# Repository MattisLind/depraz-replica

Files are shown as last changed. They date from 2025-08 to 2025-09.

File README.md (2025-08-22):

# Depraz mouse replica

Based on the work by John Floren this project is aiming at creating a modern replica of the Depraz mouse. A mouse that outputs quadrature signals exactly as the original.

The physical 3D model will be the same as the Bellwether mouse by John but the circuit board is replaced. The new circuitboard is going to use an STM32F103 micro controller. Since this processor is using 3.3V IO no level shifters are necessary. On the board there will be a 3.3V LDO regulator and a 2.0V regulator, STM32F103 with 8MHz crystal and the PMW3389 mouse chip. The outputs from the STM32F103 to the host are using open drain to be able to handle 5V outputs. 

# Old Bellwether project

This repo should contain everything you need to make a [Bellwether mouse](https://jfloren.net/bellwether.html).

Note that I've made several of these myself, but it's possible that I've forgotten a step or component somewhere.

I'm willing to answer questions to the best of my ability. I'll also consider assembling some portions of the mouse and mailing it out; send me an email if you want this.

The 3d models and the circuit are CC BY-NC-SA licensed. I believe this means that "group buys" (where 1 person coordinates ordering a bunch of PCBs and parts) are ok under this model.

## 3D-printed case

Inside the case/ subdirectory you'll find two FreeCAD files, "base" (the bottom part of the mouse) and "body" (the curved top which fits in your hand).

These should be printed in PLA. I've had good luck with my Prusa Mini. I strongly suggest using a raft when printing the body, and *not* using a raft for the base.

Check out the releases for pre-built STL files.

## PCB

The board was designed using KiCAD. If you use OSH Park, you should be able to just upload board/depraz_board.kicad_pcb directly on their site. For other PCB services, you may need to open KiCAD and export Gerber files etc.

## Circuit & BOM

You can check out the schematic in schematic.pdf

bom.csv is a circuit bill of materials. Most stuff should be available from parts companies in the US, but for the PMW3389 sensor you'll probably need to go to AliExpress (e.g. https://www.aliexpress.us/item/2251832705021246.html)

You'll also need 3 momentary pushbutton switches such as https://www.digikey.com/en/products/detail/5501M1BLKX/EG1701-ND/101654

Although you don't have to, I recommend using a DIP socket for the microcontroller in case you toast the microcontroller.

## Assembly

### Circuit assembly

In general it's all pretty straightforward but I strongly recommend installing the SMD level shifters first, all the rest of the components next, and then do the mouse sensor *last*.

### Doing the switches

I recommend gluing down the switches first. Gently pry off the button from each switch and set it aside. Then put a small dab of Gorilla Glue in the slot on the base, press the switch onto it, and make sure it's aligned straight. Use a clamp to hold the switch in place while the glue dries (I used something like https://www.amazon.com/Professional-Plastic-Backdrop-Photography-Improvement/dp/B08RXW32H4/). Once the glue is dry, make sure the switch is firmly seated and use an exacto knife to trim away any glue which oozed out, then press the button back onto the switch face.

Solder two wires onto each switch, on the normally-open pins. The wires should have Dupont pin connectors on the ends; I just took some jumper wires I had lying around (with a connector on each end) and cut them in half. See http://jfloren.net/content/bellwether/base2.jpg

### Physical assembly

You'll need the following parts to assemble the case:

* 8x M2x0.4mm heatserts: https://www.mcmaster.com/94459A120/
* 4x M2x0.4mm flathead screws (for the bottom): https://www.mcmaster.com/91294A003/
* 4x M2x0.4mm button head screws (to hold the board down): https://www.mcmaster.com/92095A451/

Additional stuff you'll want:

* A USB cable. Should be USB-A on one end, and a female pin header connector at the other. You can start with https://www.digikey.com/en/products/detail/assmann-wsw-components/A-USB20AM-OE-200BK28/10408422 and use https://www.amazon.com/Taiss-Ratcheting-Connector-Crimping-Terminal/dp/B0B11RLGDZ to crimp on a 4-pin header to the other end. You may be able to find these pre-made, e.g. https://www.amazon.com/dp/B07ZPT2NMT
* Friction tape (https://www.amazon.com/gp/product/B0000CBIAT) to wrap around the USB cable where it leaves the mouse. This appears to be what my original Depraz mouse used.
* Teflon tape to make skates for the bottom. I used https://www.amazon.com/gp/product/B01LZ44P6M and punched out pieces using https://www.amazon.com/gp/product/B00006IBK9

Use your soldering iron to install the heatserts flush in the corresponding holes of the case.

Position the lens on the bottom of the mouse sensor, then set the PCB on the 3d printed base. Use the button-head screws to hold down the PCB; don't overtighten!

Plug in the switches. Note that the headers on the board are labeled R, M, and L for right, middle, and left.

Plug the USB cable into the 4-pin USB header. Lay it across the board to where the cable hole in the case will go; mark this point and put a layer or two of friction tape on the cable there.

Gently slide the top of the case over the switches; there's a "right way" to do it, which takes a bit of gentle experimentation to find. Once you get the two pieces together, use flathead screws to hold them together.

Punch out four pieces of Teflon tape and stick them to the bottom for skates.

### Flashing the firmware

The firmware organization sucks, but I am not good enough at PIC programming to properly clean it up. PRs welcome.

Plug your PIC programmer into the PROGRAM header on the board.

Open MPLAB X IDE and load firmware/depraz/apps/usb/device/hid_mouse/firmware/low_pin_count_usb_development_kit_pic16f1459.x

I found that it worked when I set up the PICkit3 to provide power at 3.5V. Your other option is to plug in the USB cable before programming to power the device externally.

### Adding heft

You'll probably find that the mouse by itself is way too light. I hot-glued a bunch of lead fishing weights to the inside and it was much more pleasant.

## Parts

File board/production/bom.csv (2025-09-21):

Designator | Footprint | Quantity | Value | LCSC Part #
C1, C2, C3 | 1206 | 3 | 4.7u | C29823
C10, C11, C12, C15, C4, C9 | 0402 | 6 | 100n | C1525
C14, C5 | 0805 | 2 | 1u | C28323
C6, C7 | 0402 | 2 | 20p | C1554
C8 | CP_Elec_4x5.4 | 1 | 22u | C3356
D1 | 0603 | 1 | 1.9V PWR | C2286
D2 | 0805 | 1 | 3.3V PWR | C2297
D3 | 0805 | 1 | LED | C2296
J1 | PinHeader_1x06_P2.54mm_Vertical | 1 | Switches
J2 | PinHeader_1x09_P2.54mm_Vertical | 1 | Host
J3 | PinHeader_1x04_P2.54mm_Vertical | 1 | SWD
J4 | PinHeader_1x04_P2.54mm_Vertical | 1 | SERIAL
R1, R10, R2, R3, R5, R6, R7, R8, R9 | 0402 | 9 | 2k | C4109
R11 | 0603 | 1 | 47 | C23182
R13, R14 | 0402 | 2 | 510 | C25123
R4 | 0805 | 1 | 13 | C25282
U1 | WSON-6-1EP_2x2mm_P0.65mm_EP1x1.6mm | 1 | TLV75519PDRV | C2861631
U2 | WSON-6-1EP_2x2mm_P0.65mm_EP1x1.6mm | 1 | TLV75533PDRV | C2861750
U5 | pmw3389 | 1 | PMW3389DM
U6 | LQFP-48_7x7mm_P0.5mm | 1 | STM32F103C8Tx | C8734
Y1 | Crystal_SMD_HC49-SD | 1 | 8MHz | C20617538

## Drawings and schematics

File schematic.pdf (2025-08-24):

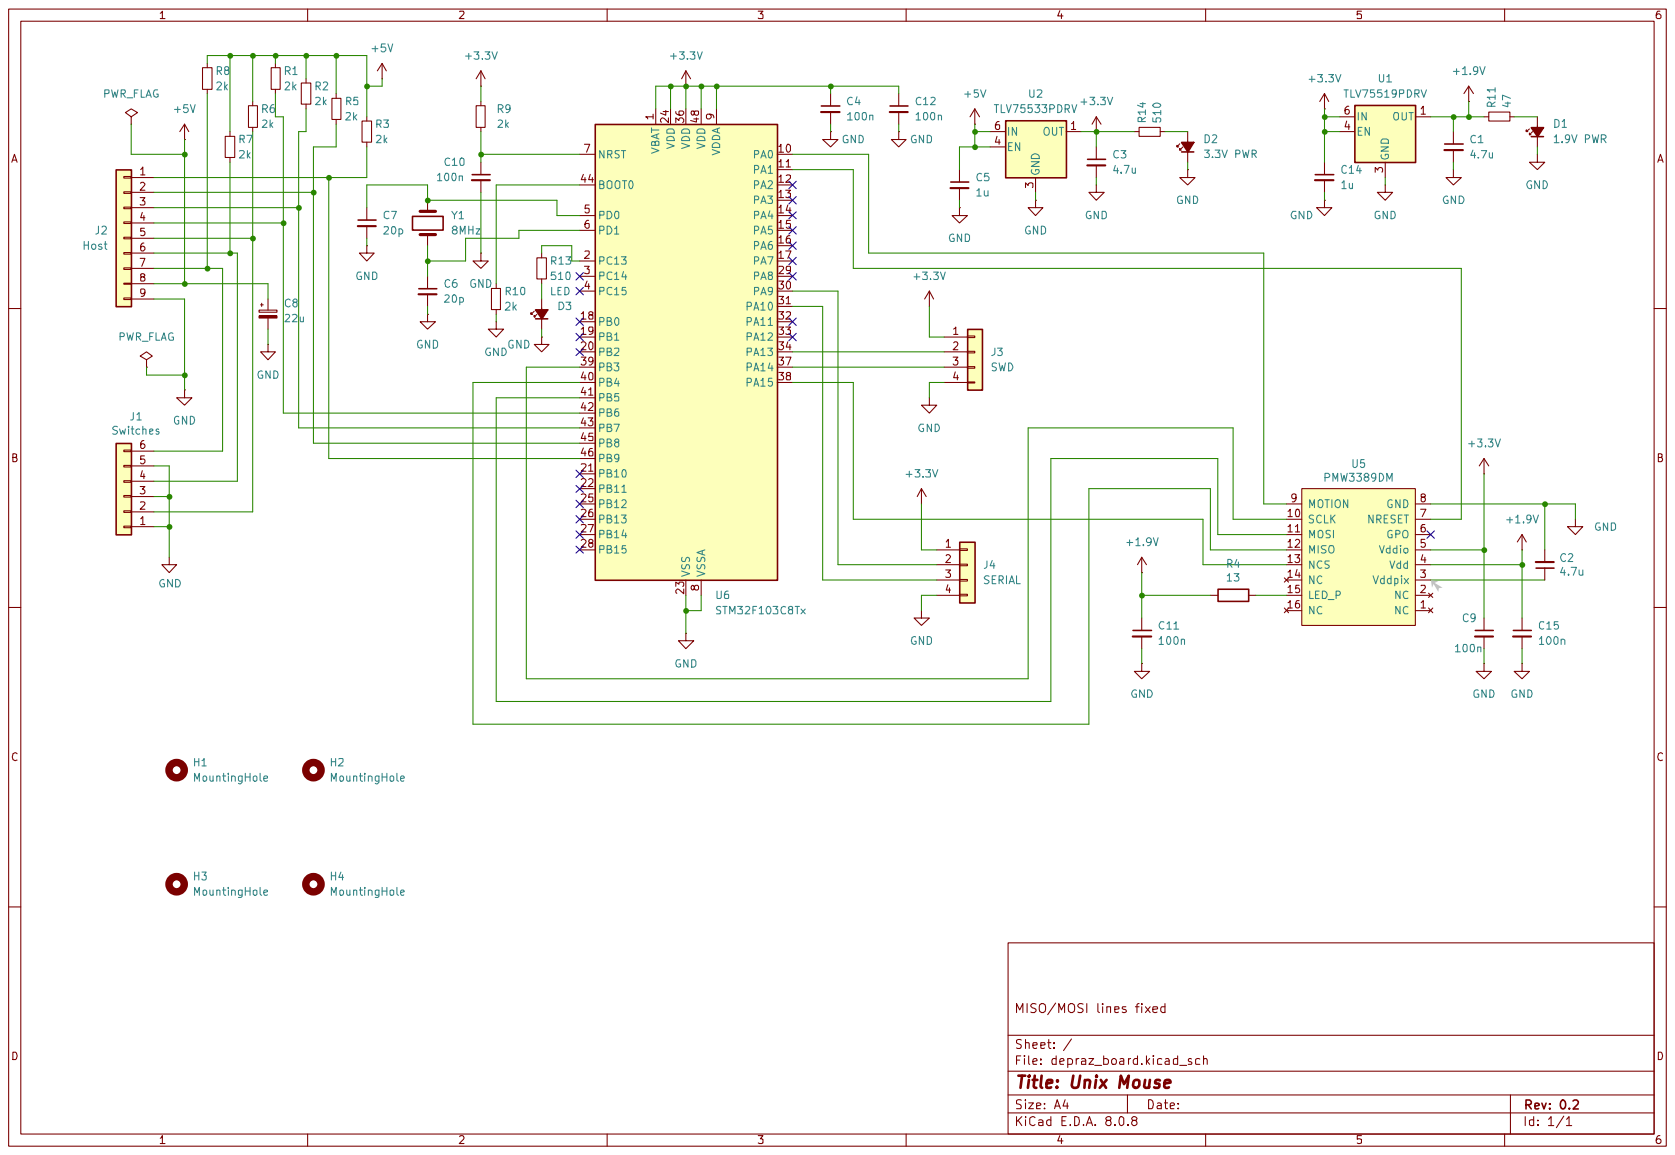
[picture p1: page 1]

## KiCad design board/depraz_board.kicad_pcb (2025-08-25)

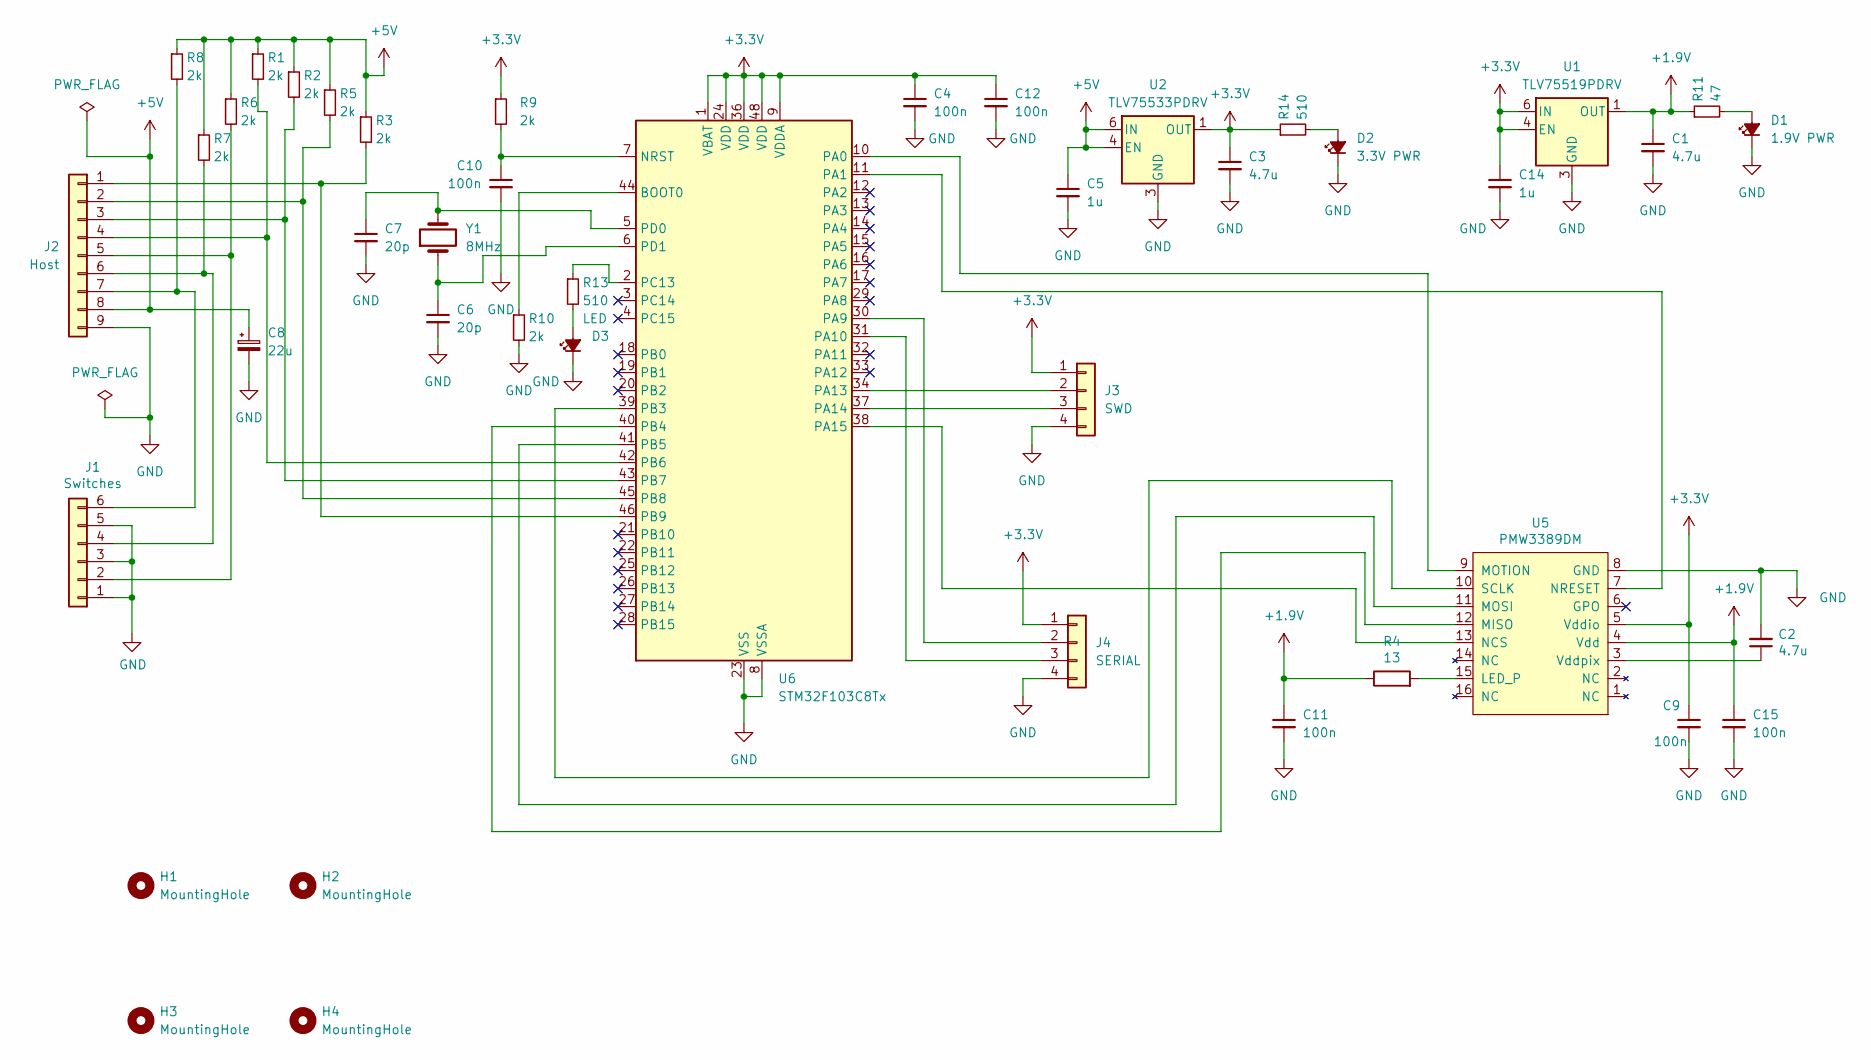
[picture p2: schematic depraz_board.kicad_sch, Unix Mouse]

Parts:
C1, C2, C3: 4.7u; C_1206_3216Metric; LCSC C29823
C4, C9, C10, C11, C12, C15: 100n; C_0402_1005Metric; LCSC C1525
C5, C14: 1u; C_0805_2012Metric; LCSC C28323
C6, C7: 20p; C_0402_1005Metric; LCSC C1554
C8: 22u; CP_Elec_4x5.4; LCSC C3356
D1: 1.9V PWR; LED_0603_1608Metric; LCSC C2286
D2: 3.3V PWR; LED_0805_2012Metric; LCSC C2297
D3: LED; LED_0805_2012Metric; LCSC C2296
H1, H2, H3, H4: MountingHole; MountingHole_2.7mm_M2.5
J1: Switches; PinHeader_1x06_P2.54mm_Vertical
J2: Host; PinHeader_1x09_P2.54mm_Vertical
J3: SWD; PinHeader_1x04_P2.54mm_Vertical
J4: SERIAL; PinHeader_1x04_P2.54mm_Vertical
R1, R2, R3, R5, R6, R7, R8, R9, R10: 2k; R_0402_1005Metric; LCSC C4109
R4: 13; R_0805_2012Metric; LCSC C25282
R11: 47; R_0603_1608Metric; LCSC C23182
R13, R14: 510; R_0402_1005Metric; LCSC C25123
U1: TLV75519PDRV; WSON-6-1EP_2x2mm_P0.65mm_EP1x1.6mm; LCSC C2861631
U2: TLV75533PDRV; WSON-6-1EP_2x2mm_P0.65mm_EP1x1.6mm; LCSC C2861750
U5: PMW3389DM; pmw3389
U6: STM32F103C8Tx; LQFP-48_7x7mm_P0.5mm; LCSC C8734
Y1: 8MHz; Crystal_SMD_HC49-SD; LCSC C20617538

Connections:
+1.9V: C1.1, C11.1, C15.1, R4.1, R11.1, U1.1 (OUT), U5.4 (Vdd)
+3.3V: C3.1, C4.1, C9.1, C12.1, C14.1, J3.1, J4.1, R9.1, R14.1, U1.4 (EN), U1.6 (IN), U2.1 (OUT), U5.5 (Vddio), U6.1 (VBAT), U6.9 (VDDA), U6.24 (VDD), U6.36 (VDD), U6.48 (VDD)
+5V: C5.1, C8.1, J2.8, R1.1, R2.1, R3.1, R5.1, R6.1, R7.1, R8.1, U2.4 (EN), U2.6 (IN)
GND: C1.2, C2.2, C3.2, C4.2, C5.2, C6.2, C7.2, C8.2, C9.2, C10.2, C11.2, C12.2, C14.2, C15.2, D1.1 (K), D2.1 (K), D3.1 (K), J1.1, J1.3, J1.5, J2.9, J3.4, J4.4, R10.2, U1.3 (GND), U1.7 (GND), U2.3 (GND), U2.7 (GND), U5.8 (GND), U6.8 (VSSA), U6.23 (VSS), U6.35 (VSS), U6.47 (VSS)
unnamed: D1.2 (A), R11.2
unnamed: D2.2 (A), R14.2
unnamed: D3.2 (A), R13.2
unnamed: J1.2, J2.5, R6.2
unnamed: J1.4, J2.6, R7.2
unnamed: J1.6, J2.7, R8.2
unnamed: J2.1, R3.2, U6.46 (PB9)
unnamed: J2.2, R5.2, U6.45 (PB8)
unnamed: J2.3, R2.2, U6.43 (PB7)
unnamed: J2.4, R1.2, U6.42 (PB6)
unnamed: J3.2, U6.34 (PA13)
unnamed: J3.3, U6.37 (PA14)
unnamed: J4.2, U6.30 (PA9)
unnamed: J4.3, U6.31 (PA10)
unnamed: R4.2, U5.15 (LED_P)
unnamed: U5.12 (MISO), U6.40 (PB4)
unnamed: U5.11 (MOSI), U6.41 (PB5)
unnamed: U5.9 (MOTION), U6.10 (PA0)
unnamed: U5.13 (NCS), U6.38 (PA15)
unnamed: U5.7 (NRESET), U6.11 (PA1)
unnamed: U5.10 (SCLK), U6.39 (PB3)
unnamed: C2.1, U5.3 (Vddpix)
unnamed: R10.1, U6.44 (BOOT0)
unnamed: C10.1, R9.2, U6.7 (NRST)
unnamed: R13.1, U6.2 (PC13)
unnamed: C7.1, U6.5 (PD0), Y1.2
unnamed: C6.1, U6.6 (PD1), Y1.1

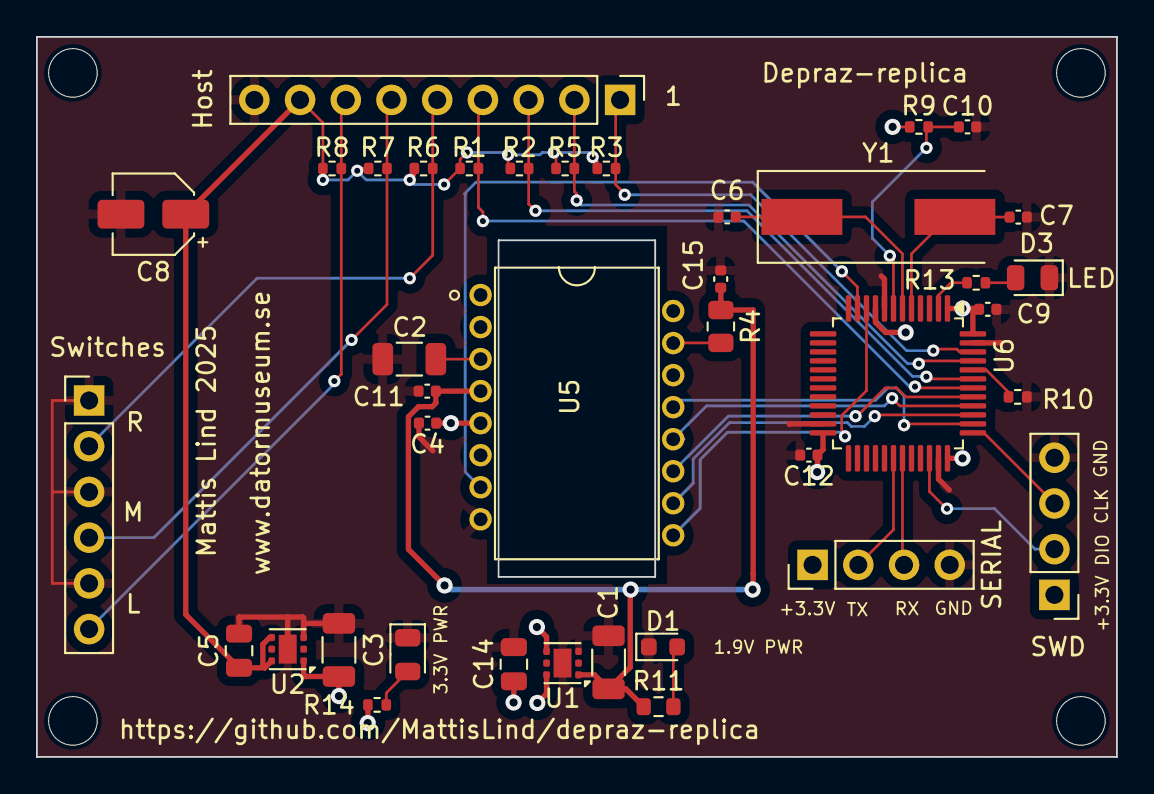
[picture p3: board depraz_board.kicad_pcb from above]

Board: 2 copper layers, 60.0 x 40.0 mm, 43 parts (0 on the bottom side), 31 nets.

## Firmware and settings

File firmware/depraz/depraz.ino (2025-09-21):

/*

  First attempt as created by ChatGPT. Interesting to see how this works. If it even compile...

  PMW3389 → Quadrature bridge (init aligned with depraz demo main.c)

  Init flow (like your demo):
    1) Read ProductID
    2) Read Motion + DeltaX/DeltaY (clear state)
    3) Write resolution (CPI) to CONFIG1
    4) Write Motion register (value configurable below)
    5) Enter loop reading deltas

  Hardware (STM32, Arduino_Core_STM32):
    - SPI1: PB3=SCK, PB4=MISO, PB5=MOSI; NCS=PA15
    - MOTION=PA0 (input), NRESET=PA1 (output)
    - Quadrature out: X1=PB6, X2=PB7, Y1=PB8, Y2=PB9
    - LED: PC13 (active-low on many boards)
    - Debug UART: USART1 on PA9/PA10 (define DEBUG_SERIAL 1 to enable)
    - JTAG disabled, SWD kept enabled

  NOTE: Many PMW33xx designs require SROM upload after reset for valid motion.
        Your demo’s simple init works on your board/firmware; we follow that here.
*/

#include <SPI.h>

// ------------------------- Compile-time configuration ------------------

// Enable/disable serial debug (USART1 PA9/PA10)
#define DEBUG_SERIAL 1

// Desired resolution in CPI; PMW3389 uses 50-CPI steps via CONFIG1
#define DESIRED_CPI 1600

// Value to write to MOTION register in init step (match your demo).
// If your original code used another value, change here.
#define MOTION_WRITE_VAL 0x00

// Quadrature pulse width per half-step (µs)
#define QUAD_PULSE_US 20

// Sample rate 100 Hz = 10 ms
#define SAMPLE_PERIOD_MS 10

// ------------------------- Pin assignments -----------------------------

const uint8_t PIN_NCS    = PA15; // PMW3389 NCS
const uint8_t PIN_MOTION = PA0;  // PMW3389 MOTION (interrupt)
const uint8_t PIN_NRESET = PA1;  // PMW3389 NRESET (output)

const uint8_t PIN_X1 = PB6; // Quadrature X A
const uint8_t PIN_X2 = PB7; // Quadrature X B
const uint8_t PIN_Y1 = PB8; // Quadrature Y A
const uint8_t PIN_Y2 = PB9; // Quadrature Y B

const uint8_t PIN_LED = PC13;

// ------------------------- PMW3389 register map (subset) ---------------

// Common PMW33xx regs; names per datasheet family
#define REG_PRODUCT_ID     0x00
#define REG_REVISION_ID    0x01
#define REG_MOTION         0x02
#define REG_DELTA_X_L      0x03
#define REG_DELTA_X_H      0x04
#define REG_DELTA_Y_L      0x05
#define REG_DELTA_Y_H      0x06
#define REG_CONFIG1        0x0F  // CPI = value*50 (range 1..0xFF depending on model)

// ------------------------- Globals/state --------------------------------

volatile bool motionFlag = false;     // set in MOTION ISR
uint8_t quadStateX = 0;               // 2-bit Gray state
uint8_t quadStateY = 0;
uint32_t lastSampleMs = 0;

// ------------------------- HAL: disable JTAG, keep SWD ------------------


static void disableJTAG_keepSWD() {
  // Frigör PB3/PB4/PB5 för SPI men behåll SWD för debug/programmering
  __HAL_AFIO_REMAP_SWJ_NOJTAG();
}

// ------------------------- LED helpers ----------------------------------

inline void ledOn() {
  digitalWrite(PIN_LED, HIGH);
}

inline void ledOff() {
  digitalWrite(PIN_LED, LOW);
}

// ------------------------- SPI helpers ----------------------------------

inline void ncsLow()  { digitalWrite(PIN_NCS, LOW);  }
inline void ncsHigh() { digitalWrite(PIN_NCS, HIGH); }

// PMW3389 uses SPI mode 3
static uint8_t spiReadReg(uint8_t reg) {
  SPI.transfer(reg & 0x7F);          // MSB=0 for read
  delayMicroseconds(1);              // tSRAD (säker marginal)
  uint8_t v = SPI.transfer(0x00);
  delayMicroseconds(10);
  return v;
}

static void spiWriteReg(uint8_t reg, uint8_t val) {
  SPI.transfer(reg | 0x80);          // MSB=1 for write
  SPI.transfer(val);
  delayMicroseconds(10);             
}

// ------------------------- Sensor init (matches your demo) --------------

static void sensorInitSimple() {
  // (Valfri) hårdvarureset via NRESET om kopplad
  digitalWrite(PIN_NRESET, LOW);
  delay(100);
  digitalWrite(PIN_NRESET, HIGH);
  delay(1000);

  uint8_t pid = spiReadReg(REG_PRODUCT_ID);
  uint8_t rev = spiReadReg(REG_REVISION_ID);
#if DEBUG_SERIAL
  Serial1.print("ProductID=0x"); Serial1.print(pid, HEX);
  Serial1.print(" RevisionID=0x"); Serial1.println(rev, HEX);
#endif

  (void)spiReadReg(REG_MOTION);
  (void)spiReadReg(REG_DELTA_X_L);
  (void)spiReadReg(REG_DELTA_X_H);
  (void)spiReadReg(REG_DELTA_Y_L);
  (void)spiReadReg(REG_DELTA_Y_H);

  uint8_t cpi_val = (uint8_t)((DESIRED_CPI + 49) / 50);
  spiWriteReg(REG_CONFIG1, cpi_val);
#if DEBUG_SERIAL
  Serial1.print("CPI set to "); Serial1.print((int)cpi_val * 50);
  Serial1.print(" (CONFIG1=0x"); Serial1.print(cpi_val, HEX); Serial1.println(")");
#endif

  spiWriteReg(REG_MOTION, MOTION_WRITE_VAL);
#if DEBUG_SERIAL
  Serial1.print("Motion reg written: 0x");
  Serial1.println(MOTION_WRITE_VAL, HEX);
#endif
}


// ------------------------- Quadrature generation ------------------------

static const uint8_t graySeq[4] = { 0b00, 0b01, 0b11, 0b10 };

inline void writeXPins(uint8_t bits) {
  digitalWrite(PIN_X1, (bits & 0x01) ? HIGH : LOW); // A
  digitalWrite(PIN_X2, (bits & 0x02) ? HIGH : LOW); // B
#if DEBUG_SERIAL
  Serial1.print("X1:");
  Serial1.println(bits & 0x01, DEC);
  Serial1.print("X2:");
  Serial1.println((bits>>1) & 0x01, DEC);
#endif

}

inline void writeYPins(uint8_t bits) {
  digitalWrite(PIN_Y1, (bits & 0x01) ? HIGH : LOW); // A
  digitalWrite(PIN_Y2, (bits & 0x02) ? HIGH : LOW); // B
#if DEBUG_SERIAL
  Serial1.print("Y1:");
  Serial1.println(bits & 0x01, DEC);
  Serial1.print("Y2:");
  Serial1.println(((bits>>1) & 0x01), DEC);
#endif  
}

static void stepQuadX(int steps) {
  int n = steps;
  int dir = (n >= 0) ? +1 : -1;
  n = abs(n);
  while (n--) {
    quadStateX = (quadStateX + (dir > 0 ? 1 : 3)) & 0x03;
    writeXPins(graySeq[quadStateX]);
    delayMicroseconds(QUAD_PULSE_US);
  }
}

static void stepQuadY(int steps) {
  int n = steps;
  int dir = (n >= 0) ? +1 : -1;
  n = abs(n);
  while (n--) {
    quadStateY = (quadStateY + (dir > 0 ? 1 : 3)) & 0x03;
    writeYPins(graySeq[quadStateY]);
    delayMicroseconds(QUAD_PULSE_US);
  }
}

// ------------------------- Read deltas at 100 Hz ------------------------

static void readDeltas(int16_t &dx, int16_t &dy) {
  uint8_t motion = spiReadReg(REG_MOTION);
  uint8_t xl = spiReadReg(REG_DELTA_X_L);
  uint8_t xh = spiReadReg(REG_DELTA_X_H);
  uint8_t yl = spiReadReg(REG_DELTA_Y_L);
  uint8_t yh = spiReadReg(REG_DELTA_Y_H);

  dx = (int16_t)(((int16_t)xh << 8) | xl);
  dy = (int16_t)(((int16_t)yh << 8) | yl);

#if DEBUG_SERIAL
  // Enkel spårning av MOTION-bit för diagnos
  //Serial1.print("MOTION=0x"); Serial1.print(motion, HEX);
  //Serial1.print(" dx="); Serial1.print(dx);
  //Serial1.print(" dy="); Serial1.println(dy);
#endif
}

// ------------------------- Setup / Loop ---------------------------------

void setup() {
  disableJTAG_keepSWD();

  // LED
  pinMode(PIN_LED, OUTPUT);
  ledOff();

  // Quadrature outputs are open drain
  pinMode(PIN_X1, OUTPUT_OPEN_DRAIN);
  pinMode(PIN_X2, OUTPUT_OPEN_DRAIN);
  pinMode(PIN_Y1, OUTPUT_OPEN_DRAIN);
  pinMode(PIN_Y2, OUTPUT_OPEN_DRAIN);
  writeXPins(graySeq[quadStateX]);
  writeYPins(graySeq[quadStateY]);

  pinMode(PIN_NCS, OUTPUT);   ncsHigh();
  pinMode(PIN_NRESET, OUTPUT); digitalWrite(PIN_NRESET, HIGH);


#if DEBUG_SERIAL
  Serial1.begin(115200);
  delay(10);
  Serial1.println("\nPMW3389 → Quadrature");
#endif

  SPI.setMISO(PB4);
  SPI.setMOSI(PB5);
  SPI.setSCLK(PB3);
  SPI.setSSEL(PA15);
  SPI.begin();
  SPI.beginTransaction(SPISettings(2000000, MSBFIRST, SPI_MODE3));
  sensorInitSimple();

  lastSampleMs = millis();
}

void loop() {
  uint32_t now = millis();

  if ((uint32_t)(now - lastSampleMs) >= SAMPLE_PERIOD_MS) {
    lastSampleMs += SAMPLE_PERIOD_MS;

    int16_t dx = 0, dy = 0;
    readDeltas(dx, dy);

    if (dx != 0 || dy != 0) {
      ledOn();
      stepQuadX(dx); 
      stepQuadY(dy);
      ledOff();
    } 

  }

  delay(1);
}

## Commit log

2025-08-23 New layout for a STM32 based Depraz replica with quadrature outputs.
    [depraz_board.kicad_pcb, depraz_board.kicad_sch, depraz_board.sch]
2025-08-23 Updated schematic.
2025-08-23 Added LCSC part numbers for the SMD parts.
    [depraz_board.kicad_sch]
2025-08-24 Fixes after review.
    [depraz_board.kicad_pcb, depraz_board.kicad_sch]
2025-08-24 Fixed PCB
    [depraz_board.kicad_pcb]
2025-08-25 Fixed layout after review.
    [depraz_board.kicad_pcb, depraz_board.kicad_sch]
2025-09-21 Update depraz.ino
    We use the New Arduino_STM32_Core instead of maple since it is getting old.
2025-09-21 Fixed SPI pin routing
    Compiles and seems to actually do something useful. The SPI pins was not routed correctly.
    [depraz.ino]
2025-09-21 Added JLCPCB production files.
    [bom.csv, designators.csv, positions.csv]
